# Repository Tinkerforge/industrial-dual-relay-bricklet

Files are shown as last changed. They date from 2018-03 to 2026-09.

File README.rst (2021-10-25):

Industrial Dual Relay Bricklet
==============================

This repository contains the firmware source code and the hardware design
files. The documentation generator configs can be found at
https://github.com/Tinkerforge/generators

Repository Content
------------------

software/:
 * examples/: Examples for all supported languages
 * build/: Compiled files
 * src/: Source code of firmware
 * Makefile: Makefile to build project

hardware/:
 * Contains KiCad project files and additionally schematics as PDF

datasheets/:
 * Contains datasheets for sensors and complex ICs that are used

Hardware
--------

The hardware is designed with the open source EDA Suite KiCad
(http://www.kicad.org). Before you are able to open the files,
you have to install the Tinkerforge kicad-libraries
(https://github.com/Tinkerforge/kicad-libraries). You can either clone
them directly in hardware/ or clone them in a separate folder and
symlink them into hardware/
(ln -s kicad_path/kicad-libraries project_path/hardware). After that you
can open the .pro file in hardware/ with KiCad and from there view and
modify the schematics and the PCB layout.

Software
--------

If you want to do your own Brick/Bricklet firmware development we highly
recommend that you use our build environment setup script and read the
tutorial (https://www.tinkerforge.com/en/doc/Tutorials/Tutorial_Build_Environment/Tutorial.html).

To compile the C code we recommend you to install the newest GNU Arm Embedded
Toolchain (https://launchpad.net/gcc-arm-embedded/+download).
You also need to install bricklib2 (https://github.com/Tinkerforge/bricklib2).

You can either clone it directly in software/src/ or clone it in a
separate folder and symlink it into software/src/
(ln -s bricklib_path/bricklib2 project_path/software/src/). Finally make sure to
have CMake installed (http://www.cmake.org/cmake/resources/software.html).

After that you can build the firmware by invoking make in software/.
The firmware (.zbin) can then be found in software/build/ and uploaded
with brickv (click button "Flashing" on start screen).

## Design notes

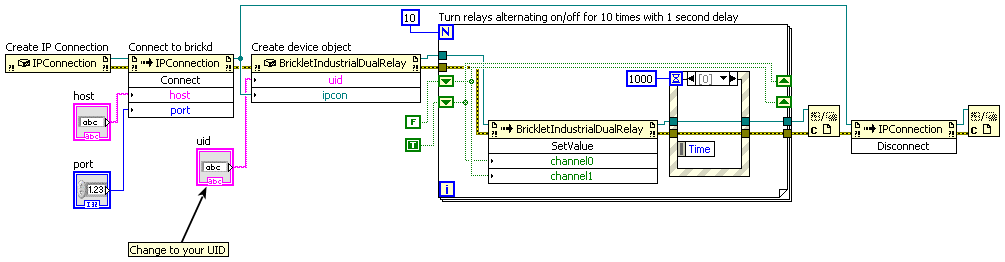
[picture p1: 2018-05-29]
software/examples/labview/Example Simple.vi.png

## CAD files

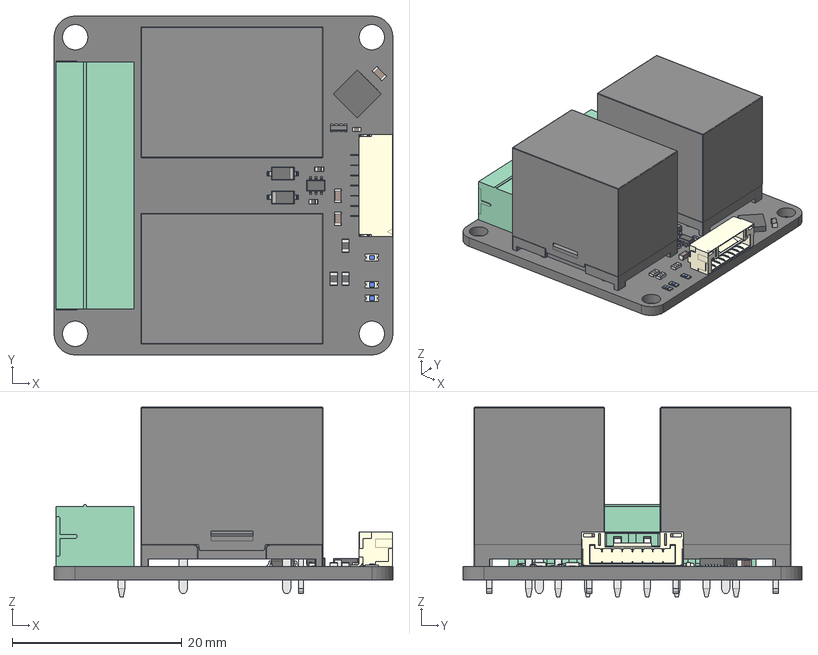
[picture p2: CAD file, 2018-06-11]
hardware/industrial-dual-relay.step
40.0 x 40.0 x 22.4 mm

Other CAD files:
hardware/industrial-dual-relay.FCStd

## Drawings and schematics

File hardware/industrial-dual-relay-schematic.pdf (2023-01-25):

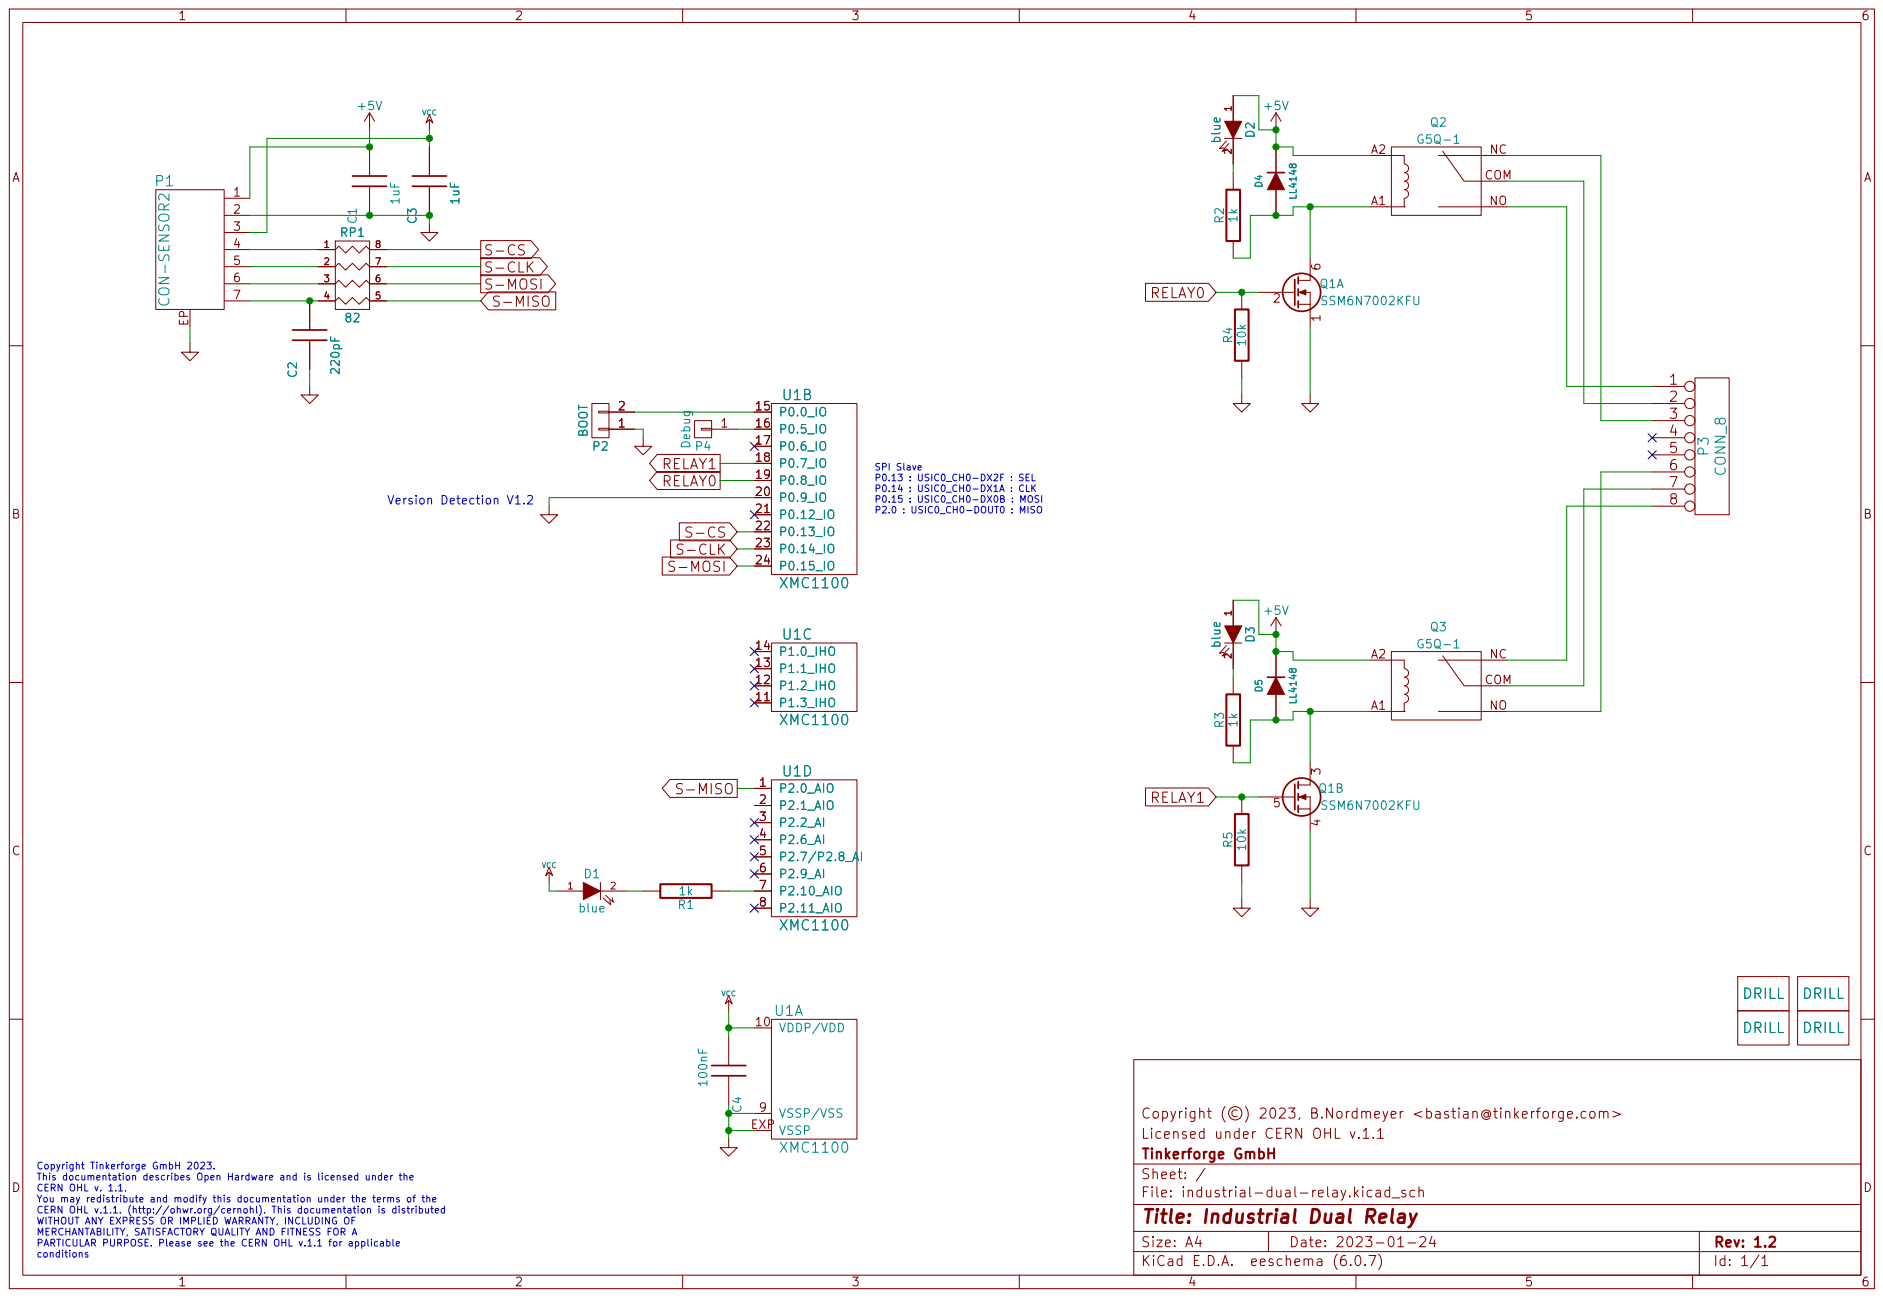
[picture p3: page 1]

SPI Slave P0.13 : USIC0_CH0-DX2F : SEL P0.14 : USIC0_CH0-DX1A : CLK

Version Detection V1.2 Copyright Tinkerforge GmbH 2023. This documentation describes Open Hardware and is licensed under the CERN OHL v. 1.1. You may redistribute and modify this documentation under the terms of the CERN OHL v.1.1. (http://ohwr.org/cernohl). This documentation is distributed WITHOUT ANY EXPRESS OR IMPLIED WARRANTY, INCLUDING OF MERCHANTABILITY, SATISFACTORY QUALITY AND FITNESS FOR A

1 2 DRILL DRILL DRILL DRILL

Licensed under CERN OHL v.1.1
File: industrial-dual-relay.kicad_sch Sheet: / Tinkerforge GmbH

Id: 1/1 Title: Industrial Dual Relay

PARTICULAR PURPOSE. Please see the CERN OHL v.1.1 for applicable
conditions

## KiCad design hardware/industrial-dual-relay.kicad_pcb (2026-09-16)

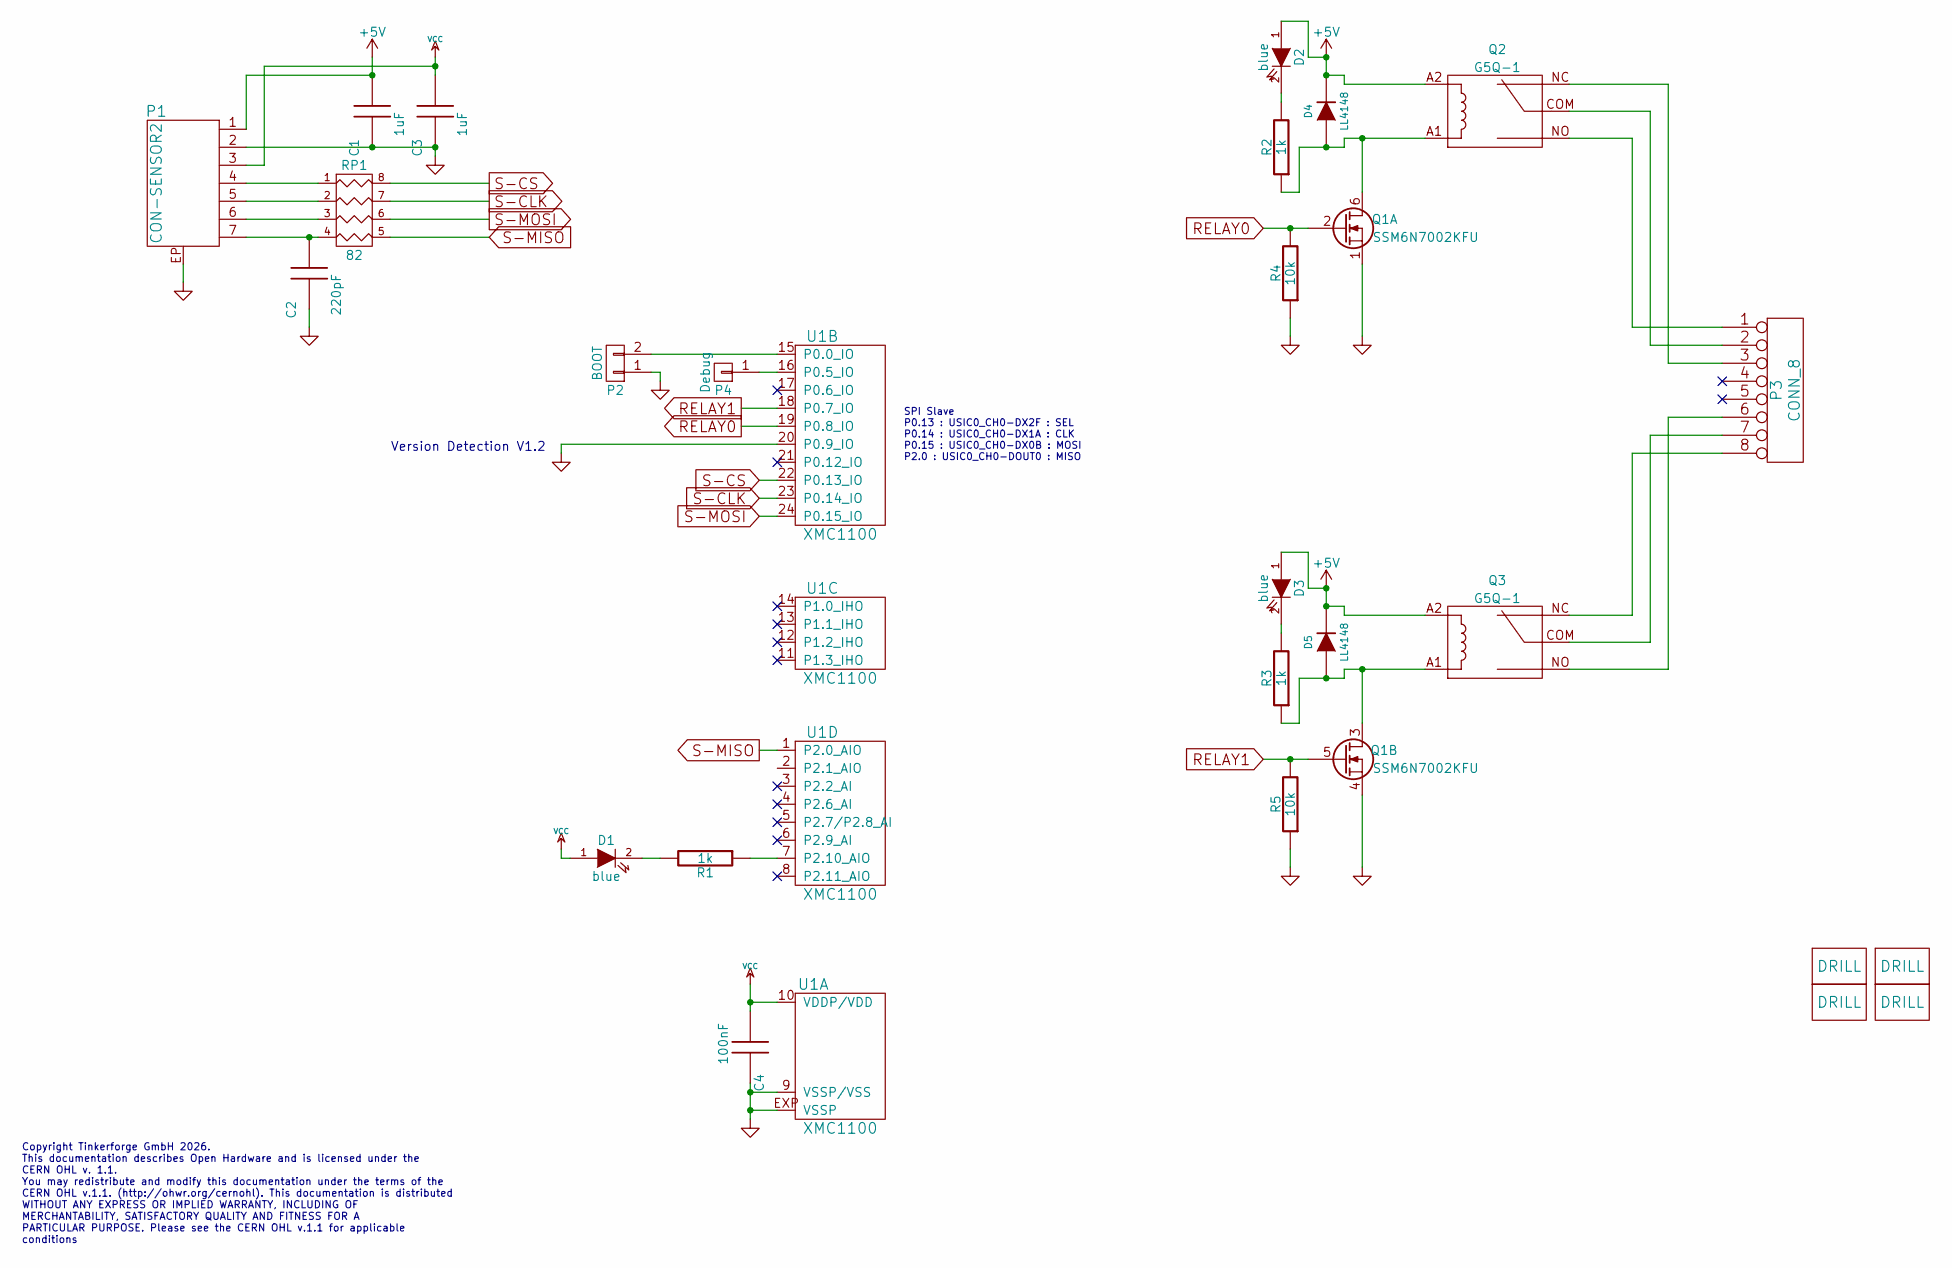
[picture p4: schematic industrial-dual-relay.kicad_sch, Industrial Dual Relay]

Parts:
C1, C3: 1uF; C0603F
C2: 220pF; C0402F
C4: 100nF; C0603F
D1, D2, D3: blue; D0603E
D4, D5: LL4148; MiniMelf
P1: CON-SENSOR2
P2: BOOT; SolderJumper
P3: CONN_8; OQ_8P_230V
P4: Debug; DEBUG_PAD
Q1: SSM6N7002KFU; SOT363
Q2, Q3: G5Q-1
R1, R2, R3: 1k; R0603F
R4, R5: 10k; R0402F
RP1: 82; 4X0402
U1: XMC1100; QFN24-4x4mm-0.5mm
U4, U5, U6, U7: DRILL; DRILL_NP

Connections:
+5V: C1.2, D2.1 (A), D3.1 (A), D4.2 (K), D5.2 (K), P1.1, Q2.A2, Q3.A2
GND: C1.1, C2.1, C3.1, C4.2, P1.2, P1.EP, P2.1, Q1.1 (S1), Q1.4 (S2), R4.1, R5.1, U1.9 (VSSP/VSS), U1.20 (P0.9_IO), U1.EXP (VSSP)
unnamed: D1.2 (K), R1.2
unnamed: D2.2 (K), R2.2
unnamed: D3.2 (K), R3.2
unnamed: D4.1 (A), Q1.6 (D1), Q2.A1, R2.1
unnamed: D5.1 (A), Q1.3 (D2), Q3.A1, R3.1
unnamed: P2.2, U1.15 (P0.0_IO)
unnamed: P3.1, Q2.NO
unnamed: P3.2, Q2.COM
unnamed: P3.3, Q2.NC
unnamed: P3.6, Q3.NO
unnamed: P3.7, Q3.COM
unnamed: P3.8, Q3.NC
unnamed: P4.1, U1.16 (P0.5_IO)
unnamed: P1.4, RP1.1
unnamed: P1.5, RP1.2
unnamed: P1.6, RP1.3
unnamed: C2.2, P1.7, RP1.4
unnamed: R1.1, U1.7 (P2.10_AIO)
RELAY0: Q1.2 (G1), R4.2, U1.19 (P0.8_IO)
RELAY1: Q1.5 (G2), R5.2, U1.18 (P0.7_IO)
S-CLK: RP1.7 (R2), U1.23 (P0.14_IO)
S-CS: RP1.8 (R1), U1.22 (P0.13_IO)
S-MISO: RP1.5 (R4), U1.1 (P2.0_AIO)
S-MOSI: RP1.6 (R3), U1.24 (P0.15_IO)
VCC: C3.2, C4.1, D1.1 (A), P1.3, U1.10 (VDDP/VDD)

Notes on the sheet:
Copyright Tinkerforge GmbH 2026. This documentation describes Open Hardware and is licensed under the CERN OHL v. 1.1. You may redistribute and modify this documentation under the terms of the CERN OHL v.1.1. (http://ohwr.org/cernohl). This documentation is distributed WITHOUT ANY EXPRESS OR IMPLIE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
SPI Slave P0.13 : USIC0_CH0-DX2F : SEL P0.14 : USIC0_CH0-DX1A : CLK P0.15 : USIC0_CH0-DX0B : MOSI P2.0 : USIC0_CH0-DOUT0 : MISO
Version Detection V1.2

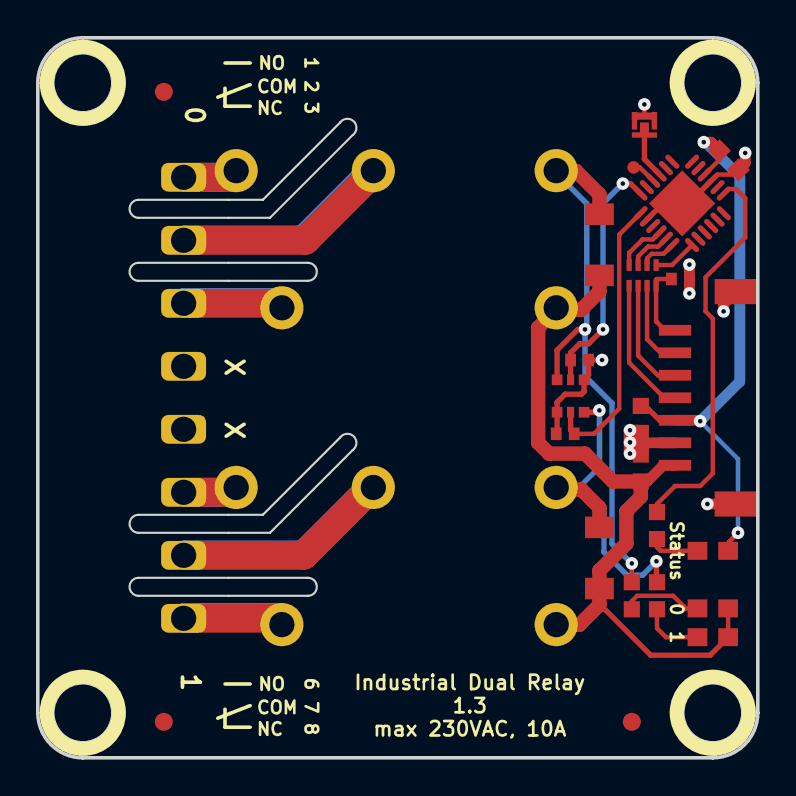
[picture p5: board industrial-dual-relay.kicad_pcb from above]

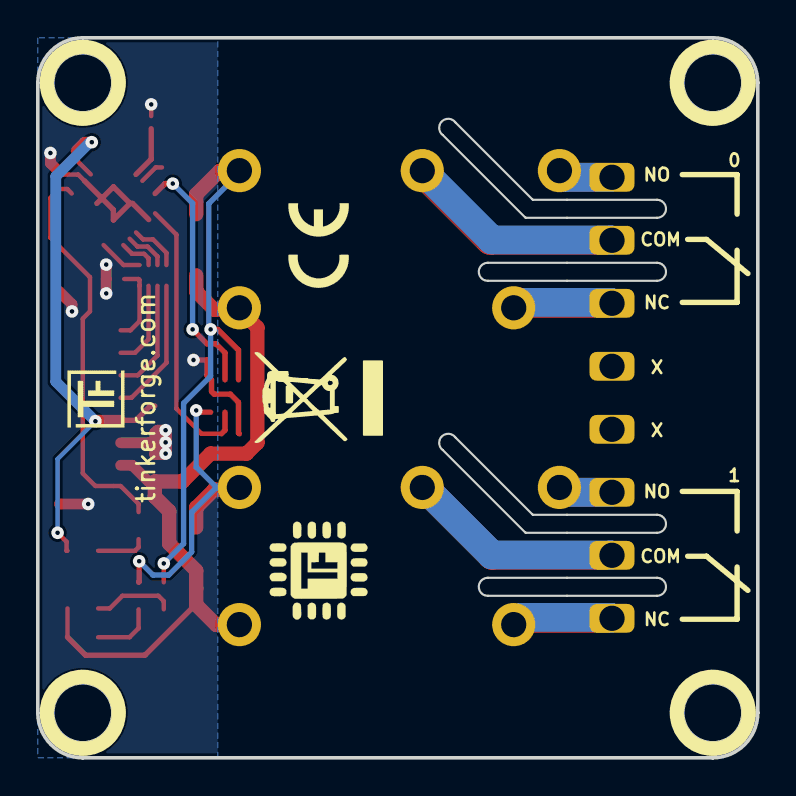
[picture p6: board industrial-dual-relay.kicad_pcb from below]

Board: 2 copper layers, 40.0 x 40.0 mm, 32 parts (2 on the bottom side), 27 nets.

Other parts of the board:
Fiducial_Mark: VAL**; Fiducial_Mark
Fiducial_Mark#2, Fiducial_Mark#3: VAL**; Fiducial_Mark
VAL: CE_5mm
VAL#2: WEEE_7mm

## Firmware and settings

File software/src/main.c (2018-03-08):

/* industrial-dual-relay-bricklet
 * Copyright (C) 2017-2018 Olaf Lüke <olaf@tinkerforge.com>
 *
 * main.c: Initialization for Dual Relay V2 Bricklet
 *
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
 * You should have received a copy of the GNU Lesser General Public
 * License along with this library; if not, write to the
 * Free Software Foundation, Inc., 59 Temple Place - Suite 330,
 * Boston, MA 02111-1307, USA.
 */

#include <stdio.h>
#include <stdbool.h>

#include "configs/config.h"

#include "bricklib2/bootloader/bootloader.h"
#include "bricklib2/hal/system_timer/system_timer.h"
#include "communication.h"
#include "relay.h"

Relay relay;

int main(void) {
	relay_init(&relay);
	communication_init();

	while(true) {
		bootloader_tick();
		communication_tick();
		relay_tick(&relay);
	}
}

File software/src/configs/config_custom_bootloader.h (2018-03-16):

/* industrial-dual-relay-bricklet
 * Copyright (C) 2017-2018 Olaf Lüke <olaf@tinkerforge.com>
 *
 * config_custom_bootloader.h: Bootloader configurations for 
 *                             Industrial Dual Relay Bricklet
 *
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
 * You should have received a copy of the GNU Lesser General Public
 * License along with this library; if not, write to the
 * Free Software Foundation, Inc., 59 Temple Place - Suite 330,
 * Boston, MA 02111-1307, USA.
 */

#ifndef CONFIG_CUSTOM_BOOTLOADER_H
#define CONFIG_CUSTOM_BOOTLOADER_H

#include "xmc_gpio.h"

// --- Basic defines ---
#define BOOTLOADER_DEVICE_IDENTIFIER   284
#define BOOTLOADER_HW_VERSION_MAJOR    1
#define BOOTLOADER_HW_VERSION_MINOR    0
#define BOOTLOADER_HW_VERSION_REVISION 0

#define BOOTLOADER_STATUS_LED_PIN      P2_10
#define BOOTLOADER_BOOT_PAD_PIN        P0_0

#define BOOTLOADER_FLASH_EEPROM_SIZE   (4*256)
#define BOOTLOADER_FLASH_SIZE          (16*1024 - BOOTLOADER_FLASH_EEPROM_SIZE)

// --- SPITFP ---
#define SPITFP_USIC_CHANNEL         USIC0_CH0
#define SPITFP_USIC                 XMC_SPI0_CH0

#define SPITFP_SCLK_PIN             P0_14
#define SPITFP_SCLK_INPUT           XMC_USIC_CH_INPUT_DX1
#define SPITFP_SCLK_SOURCE          0b000 // DX1A

#define SPITFP_SELECT_PIN           P0_13
#define SPITFP_SELECT_INPUT         XMC_USIC_CH_INPUT_DX2
#define SPITFP_SELECT_SOURCE        0b101 // DX2F

#define SPITFP_MOSI_PIN             P0_15
#define SPITFP_MOSI_INPUT           XMC_USIC_CH_INPUT_DX0
#define SPITFP_MOSI_SOURCE          0b001 // DX0B

#define SPITFP_MISO_PIN             P2_0
#define SPITFP_MISO_PIN_AF          (XMC_GPIO_MODE_OUTPUT_PUSH_PULL_ALT6 | P2_0_AF_U0C0_DOUT0)

#define SPITFP_RECEIVE_BUFFER_SIZE  1024
#define SPITFP_RECEIVE_BUFFER_MASK  (SPITFP_RECEIVE_BUFFER_SIZE-1) // If size is power of 2

#define SPITFP_SERVICE_REQUEST_RX   0
#define SPITFP_SERVICE_REQUEST_TX   1

#define SPITFP_IRQ_RX               9
#define SPITFP_IRQ_RX_PRIORITY      2
#define SPITFP_IRQ_TX               10
#define SPITFP_IRQ_TX_PRIORITY      3

#define SPITFP_TX_DATA_POINTER      16
#define SPITFP_TX_SIZE              XMC_USIC_CH_FIFO_SIZE_16WORDS
#define SPITFP_TX_LIMIT             8

#define SPITFP_RX_DATA_POINTER      0
#define SPITFP_RX_SIZE              XMC_USIC_CH_FIFO_SIZE_16WORDS
#define SPITFP_RX_LIMIT             0

// --- BOOTLOADER FUNCTIONS ---

// define bootloader functions to put them into the BootloaderFunctions struct
// These functions are in the bootloader code and can be used from the firmware

#define BOOTLOADER_FUNCTION_SPITFP_TICK
#define BOOTLOADER_FUNCTION_SEND_ACK_AND_MESSAGE
#define BOOTLOADER_FUNCTION_SPITFP_IS_SEND_POSSIBLE
#define BOOTLOADER_FUNCTION_AEABI_IDIV
#define BOOTLOADER_FUNCTION_AEABI_UIDIV
#define BOOTLOADER_FUNCTION_AEABI_IDIVMOD
#define BOOTLOADER_FUNCTION_AEABI_UIDIVMOD
#define BOOTLOADER_FUNCTION_GET_UID
#define BOOTLOADER_FUNCTION_READ_EEPROM_PAGE
#define BOOTLOADER_FUNCTION_WRITE_EEPROM_PAGE

#endif

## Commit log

2017-05-29 add status leds for relays
    [dual-relay.kicad_pcb, dual-relay.sch]
2017-05-30 Add firmware implementation
    [cmake_config_custom.txt]
2017-12-06 industrial dual relay bricklet prototype finished
    [dual-relay.kicad_pcb, dual-relay.sch]
2017-12-06 fix description text
    [dual-relay.kicad_pcb]
2018-01-22 specify values
    [dual-relay.kicad_pcb, dual-relay.sch]
2018-02-20 Cleanup KiCad libraries config
    Ensure LibDir=kicad-libraries and LibName1=tinkerforge.
    Remove special library.
2018-03-08 Change name to Industrial dual Relay
2018-03-08 fix mosfet footprint
    [dual-relay.kicad_pcb, dual-relay.sch]
2018-03-15 fix logo positions
    [dual-relay.kicad_pcb]
2018-03-16 fix tf text, add version number
    [dual-relay.kicad_pcb]
2018-03-16 fix led description text
    [dual-relay.kicad_pcb]
2018-03-27 specify processor
    [dual-relay.kicad_pcb, dual-relay.sch]
2018-04-16 Add 3d information (final)
    [dual-relay.kicad_pcb]
2018-04-16 Add 3d model (*.FCStd & *.wrl)
    [dual-relay.FCStd, dual-relay.step]
2018-05-04 Rename files
    [industrial-dual-relay.FCStd, industrial-dual-relay.kicad_pcb, industrial-dual-relay.sch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]
2018-05-04 Add schematic PDF
2018-05-29 Rename state to value und relay1/2 to channel0/1
2018-06-11 Fix 3d model
    [industrial-dual-relay.FCStd, industrial-dual-relay.kicad_pcb, industrial-dual-relay.step]
2018-06-18 Assign footprints to our library and remove cache library
    [industrial-dual-relay.sch]
2020-09-02 uc: Add example driver note.
2021-10-25 Update KiCad link
    https://www.kicad.org/blog/2021/10/Avoid-links-to-former-kicad-domain/
2022-04-27 uc: Adapt to bindings changes
    [example_simple.c]
2022-11-15 move to kicad 6, fix schematic library links
    [industrial-dual-relay.kicad_pcb, industrial-dual-relay.kicad_sch, industrial-dual-relay.sch]
2022-11-15 changed footprint from 8p-oq to 8p-oq-230v
    [industrial-dual-relay.kicad_sch]
2022-11-15 Version 1.1: changed relay, more clearance
    [industrial-dual-relay.kicad_pcb, industrial-dual-relay.kicad_sch]
2022-11-16 updated diode to minimelf footprint
    [industrial-dual-relay.kicad_pcb, industrial-dual-relay.kicad_sch]
2022-11-28 fiducial mark not in f.paste layer
    [industrial-dual-relay.kicad_pcb]
2022-11-28 Version 1.2: Updated relay footprint
    [industrial-dual-relay.kicad_pcb, industrial-dual-relay.kicad_sch]
2022-11-29 Version 1.2
    [industrial-dual-relay.kicad_pcb]
2023-01-04 changed relay0 and relay1 label
    [industrial-dual-relay.kicad_sch]
2023-01-24 Data cleanup.
    [industrial-dual-relay.kicad_pcb, industrial-dual-relay.kicad_sch]
2023-01-25 Data cleanup
    [industrial-dual-relay.kicad_pcb]
2026-07-07 Version 1.3: changed just F.Silkscreen! added Pin description NO COM NC on F.Silkscreen
    [industrial-dual-relay.kicad_pcb]
2026-09-15 final version 1.3: diff 1.2 changed silkscreen
    [industrial-dual-relay.kicad_pcb, industrial-dual-relay.kicad_sch]
2026-09-16 version 1.3: fix dates and pcb rotation
    [industrial-dual-relay.kicad_pcb, industrial-dual-relay.kicad_sch]

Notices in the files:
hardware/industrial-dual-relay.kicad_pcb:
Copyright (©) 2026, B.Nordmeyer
